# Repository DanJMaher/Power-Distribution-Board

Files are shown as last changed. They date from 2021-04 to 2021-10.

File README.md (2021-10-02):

Updated 3/29/21 - Dan Maher

C++/Arduino code for Kent State's Advanced Telerobotic's Lab's WRS robot power distribution system. The system distributes switched 24V and 12V power throughout the robot, monitors voltage, and communicates over USB and Bluetooth via JSON commands and messages. The system can also be controlled locally via an onboard OLED display and menu navigation buttons. 

The included serial_comm.py program is for testing communication between a PC and the Arduino. The system can also be tested via a Bluetooth terminal app for android or IOS.

Basic use:
1) Plug in an Arduino, send the code. 
2) run serial_comm.py (for basic communication) or power_monitor_pub.py for ROS integration on the 'power' topic.

When it boots, the Arduino tries to send a JSON message via serial:
{"request":"time"}

The python program responds via serial with the current time since midnight in seconds:
{"time": 70602, "alive": true}

Afterwards, the Arduino sends a status message via serial on the interval programmed in sendInterval in setup.cpp. The python program responds with {"alive": true} so that the Arduino knows that that communication path is good. The Arduino does not send another message until it receives a response.

The serial_comm.py program is just for troubleshooting, and copies the incoming/outgoing serial messages to the console so the user can see what's being sent/received.
---------------------------------------------------------------------------
REMOTE JSON COMMANDS
---------------------------------------------------------------------------
{"relay":[bool, bool]}		-		Sets individual relays to on/off

{"time":unsigned long}		-		Sync system time with long (in seconds)

{"shutdown":"now"}		-		Shuts down the system with code "remote"

---------------------------------------------------------------------------
INCOMING JSON MESSAGES
---------------------------------------------------------------------------

{"msg":int}			-		Message number

{"time":unsigned long}		-		Current timestamp

{"voltage:[float,float]}	-		Current voltages (11.1, 22.2)

{"relay":[bool,bool]}		-		Current relay status (11.1, 22.2)

{"comm status"[bool, bool]}	-		Current comm status path 1/2 (false is communication failure)

{"SHUTDOWN":string} 		-		System is shutting down for reason:
							"auto" - low voltage
							"remote" - remote serial command
							"button" - power button was pushed

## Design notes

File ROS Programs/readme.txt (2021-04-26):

power_distro_pub.py
-------------------
Simple program that checks the serial buffer, loads it into a json document, publishes it as the ROS topic "power" and prints it to the console. Responds to the power disto board with the current time if requested, otherwise just pings back to verify that the host is active.

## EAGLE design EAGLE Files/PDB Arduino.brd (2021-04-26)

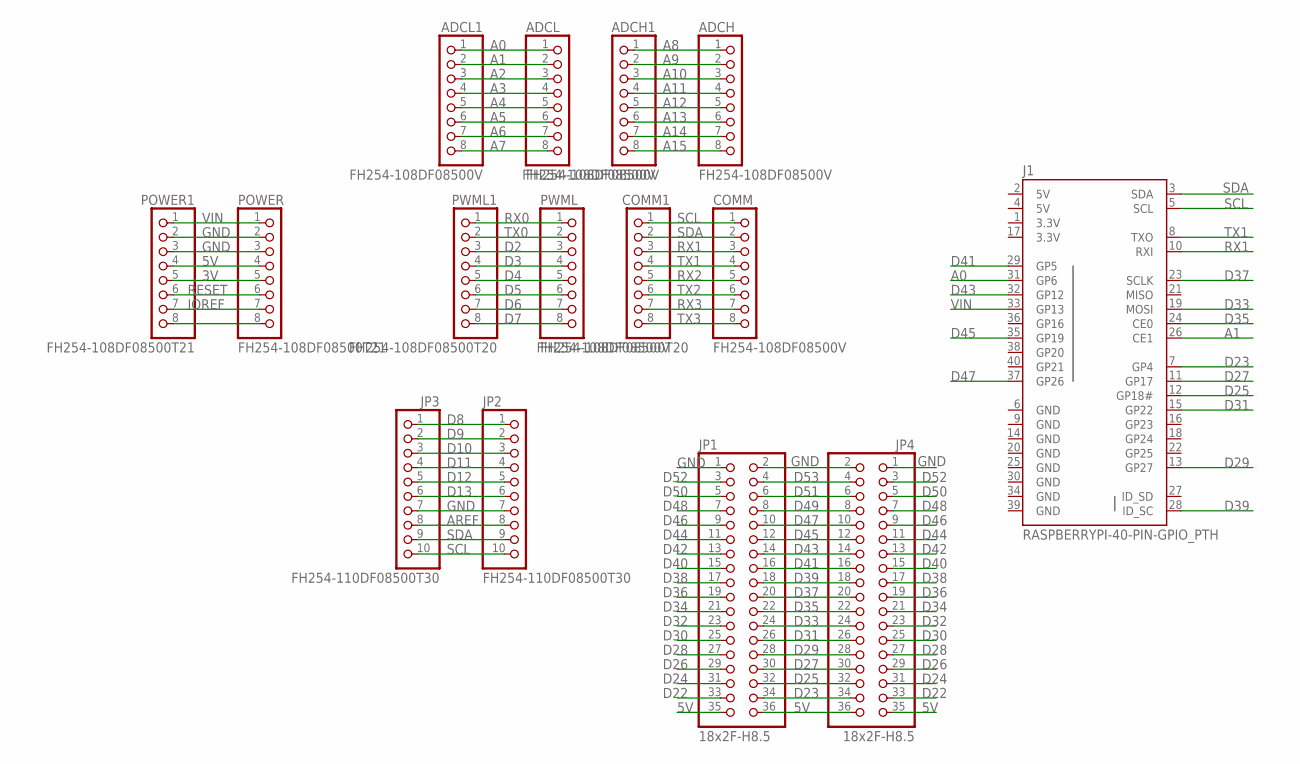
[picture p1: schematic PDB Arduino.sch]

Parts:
ADCH, ADCH1: FH254-108DF08500V; CONNETTORI_1X08
ADCL, ADCL1: FH254-108DF08500V; CONNETTORI_1X08
COMM, COMM1: FH254-108DF08500V; CONNETTORI_1X08
J1: RASPBERRYPI-40-PIN-GPIO_PTH; 2X20_SHROUDED
JP1, JP4: 18x2F-H8.5; CONNETTORI_2X18
JP2, JP3: FH254-110DF08500T30; CONNETTORI_1X10
POWER, POWER1: FH254-108DF08500T21; CONNETTORI_1X08
PWML, PWML1: FH254-108DF08500T20; CONNETTORI_1X08

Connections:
3.3V: J1.1 (3.3V), J1.17 (3.3V)
3V: POWER.5, POWER1.5
5V: J1.2 (5V), J1.4 (5V), JP1.35, JP1.36, JP4.35, JP4.36, POWER.4, POWER1.4
A0: ADCL.1, ADCL1.1, J1.31 (GP6)
A1: ADCL.2, ADCL1.2, J1.26 (CE1)
A2: ADCL.3, ADCL1.3
A3: ADCL.4, ADCL1.4
A4: ADCL.5, ADCL1.5
A5: ADCL.6, ADCL1.6
A6: ADCL.7, ADCL1.7
A7: ADCL.8, ADCL1.8
A8: ADCH.1, ADCH1.1
A9: ADCH.2, ADCH1.2
A10: ADCH.3, ADCH1.3
A11: ADCH.4, ADCH1.4
A12: ADCH.5, ADCH1.5
A13: ADCH.6, ADCH1.6
A14: ADCH.7, ADCH1.7
A15: ADCH.8, ADCH1.8
AREF: JP2.8, JP3.8
D2: PWML.3, PWML1.3
D3: PWML.4, PWML1.4
D4: PWML.5, PWML1.5
D5: PWML.6, PWML1.6
D6: PWML.7, PWML1.7
D7: PWML.8, PWML1.8
D8: JP2.1, JP3.1
D9: JP2.2, JP3.2
D10: JP2.3, JP3.3
D11: JP2.4, JP3.4
D12: JP2.5, JP3.5
D13: JP2.6, JP3.6
D22: JP1.33, JP4.33
D23: J1.7 (GP4), JP1.34, JP4.34
D24: JP1.31, JP4.31
D25: J1.12 (GP18#), JP1.32, JP4.32
D26: JP1.29, JP4.29
D27: J1.11 (GP17), JP1.30, JP4.30
D28: JP1.27, JP4.27
D29: J1.13 (GP27), JP1.28, JP4.28
D30: JP1.25, JP4.25
D31: J1.15 (GP22), JP1.26, JP4.26
D32: JP1.23, JP4.23
D33: J1.19 (MOSI), JP1.24, JP4.24
D34: JP1.21, JP4.21
D35: J1.24 (CE0), JP1.22, JP4.22
D36: JP1.19, JP4.19
D37: J1.23 (SCLK), JP1.20, JP4.20
D38: JP1.17, JP4.17
D39: J1.28 (ID_SC), JP1.18, JP4.18
D40: JP1.15, JP4.15
D41: J1.29 (GP5), JP1.16, JP4.16
D42: JP1.13, JP4.13
D43: J1.32 (GP12), JP1.14, JP4.14
D44: JP1.11, JP4.11
D45: J1.35 (GP19), JP1.12, JP4.12
D46: JP1.9, JP4.9
D47: J1.37 (GP26), JP1.10, JP4.10
D48: JP1.7, JP4.7
D49: JP1.8, JP4.8
D50: JP1.5, JP4.5
D51: JP1.6, JP4.6
D52: JP1.3, JP4.3
D53: JP1.4, JP4.4
GND: J1.6 (GND), J1.9 (GND), J1.14 (GND), J1.20 (GND), J1.25 (GND), J1.30 (GND), J1.34 (GND), J1.39 (GND), JP1.1, JP1.2, JP2.7, JP3.7, JP4.1, JP4.2, POWER.2, POWER.3, POWER1.2, POWER1.3
IOREF: POWER.7, POWER1.7
unnamed: POWER.8, POWER1.8
RESET: POWER.6, POWER1.6
RX0: PWML.1, PWML1.1
RX1: COMM.3, COMM1.3, J1.10 (RXI)
RX2: COMM.5, COMM1.5
RX3: COMM.7, COMM1.7
SCL: COMM.1, COMM1.1, J1.5 (SCL), JP2.10, JP3.10
SDA: COMM.2, COMM1.2, J1.3 (SDA), JP2.9, JP3.9
TX0: PWML.2, PWML1.2
TX1: COMM.4, COMM1.4, J1.8 (TXO)
TX2: COMM.6, COMM1.6
TX3: COMM.8, COMM1.8
VIN: J1.33 (GP13), POWER.1, POWER1.1

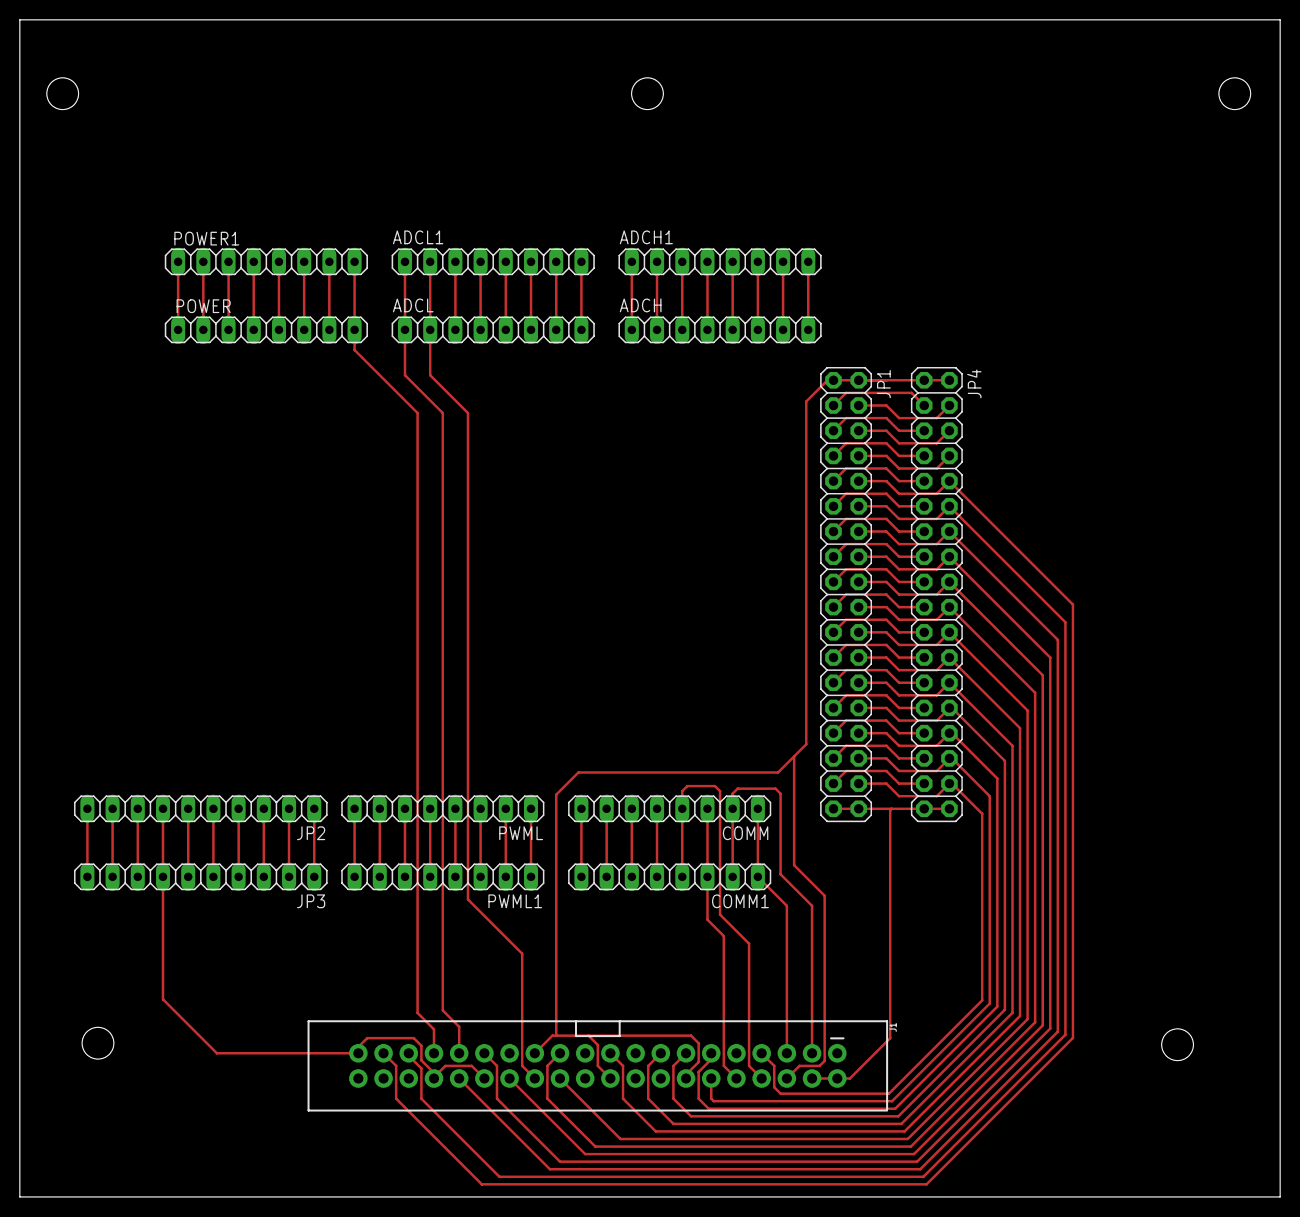
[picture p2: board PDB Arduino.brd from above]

Board: 2 copper layers, 127.0 x 118.6 mm, 15 parts (0 on the bottom side), 79 nets.

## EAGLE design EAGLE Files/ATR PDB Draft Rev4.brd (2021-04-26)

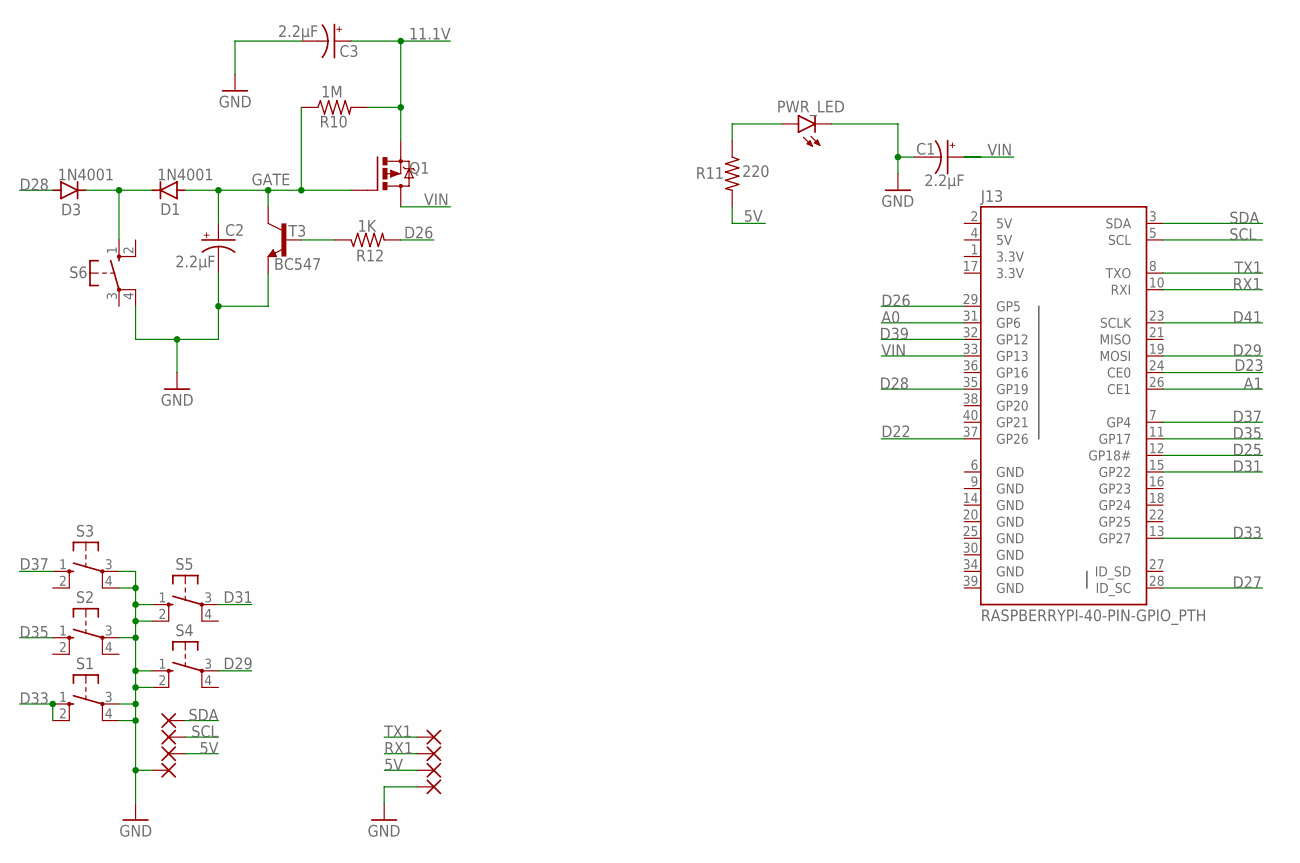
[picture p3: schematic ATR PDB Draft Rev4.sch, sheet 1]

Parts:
C1, C2, C3: 2.2µF; TT2D5
D1, D3: 1N4004; DO41-10
J13: RASPBERRYPI-40-PIN-GPIO_PTH; 2X20_SHROUDED
PAD1, PAD2, PAD3, PAD4, PAD5, PAD6, PAD7, PAD8: 1,6/0,8
PWR_LED: LED3MM
Q1: IRF9530; TO220BV
R10: 1M; 0207/10
R11: 220; 0204/7
R12: 1K; 0204/7
S1, S2, S3, S4, S5, S6: 10-XX; B3F-10XX
T3: BC547; TO92

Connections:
3.3V: J13.1 (3.3V), J13.17 (3.3V)
5V: J13.2 (5V), J13.4 (5V), PAD1.1, PAD7.1, R11.2
11.1V: C3.+, Q1.S, R10.2; also elsewhere on the board
A0: J13.31 (GP6); also elsewhere on the board
A1: J13.26 (CE1); also elsewhere on the board
D22: J13.37 (GP26); also elsewhere on the board
D23: J13.24 (CE0); also elsewhere on the board
D25: J13.12 (GP18#); also elsewhere on the board
D26: J13.29 (GP5), R12.2
D27: J13.28 (ID_SC); also elsewhere on the board
D28: D3.A, J13.35 (GP19)
D29: J13.19 (MOSI), S4.3
D31: J13.15 (GP22), S5.3
D33: J13.13 (GP27), S1.1 (S), S1.2 (S1)
D35: J13.11 (GP17), S2.1 (S)
D37: J13.7 (GP4), S3.1 (S)
D39: J13.32 (GP12); also elsewhere on the board
D41: J13.23 (SCLK); also elsewhere on the board
GATE: C2.+, D1.A, Q1.G, R10.1, T3.3 (C)
GND: C1.-, C2.-, C3.-, J13.6 (GND), J13.9 (GND), J13.14 (GND), J13.20 (GND), J13.25 (GND), J13.30 (GND), J13.34 (GND), J13.39 (GND), PAD3.1, PAD8.1, PWR_LED.K (C), S1.3, S1.4 (P1), S2.3, S3.3, S3.4 (P1), S4.1 (S), S4.2 (S1), S5.1 (S), S5.2 (S1), S6.4 (P1), T3.1 (E); also elsewhere on the board
unnamed: PWR_LED.A, R11.1
unnamed: D1.C, D3.C, S6.1 (S)
RX1: J13.10 (RXI), PAD2.1
SCL: J13.5 (SCL), PAD6.1
SDA: J13.3 (SDA), PAD5.1
T3-B: R12.1, T3.2 (B)
TX1: J13.8 (TXO), PAD4.1
VIN: C1.+, J13.33 (GP13), Q1.D

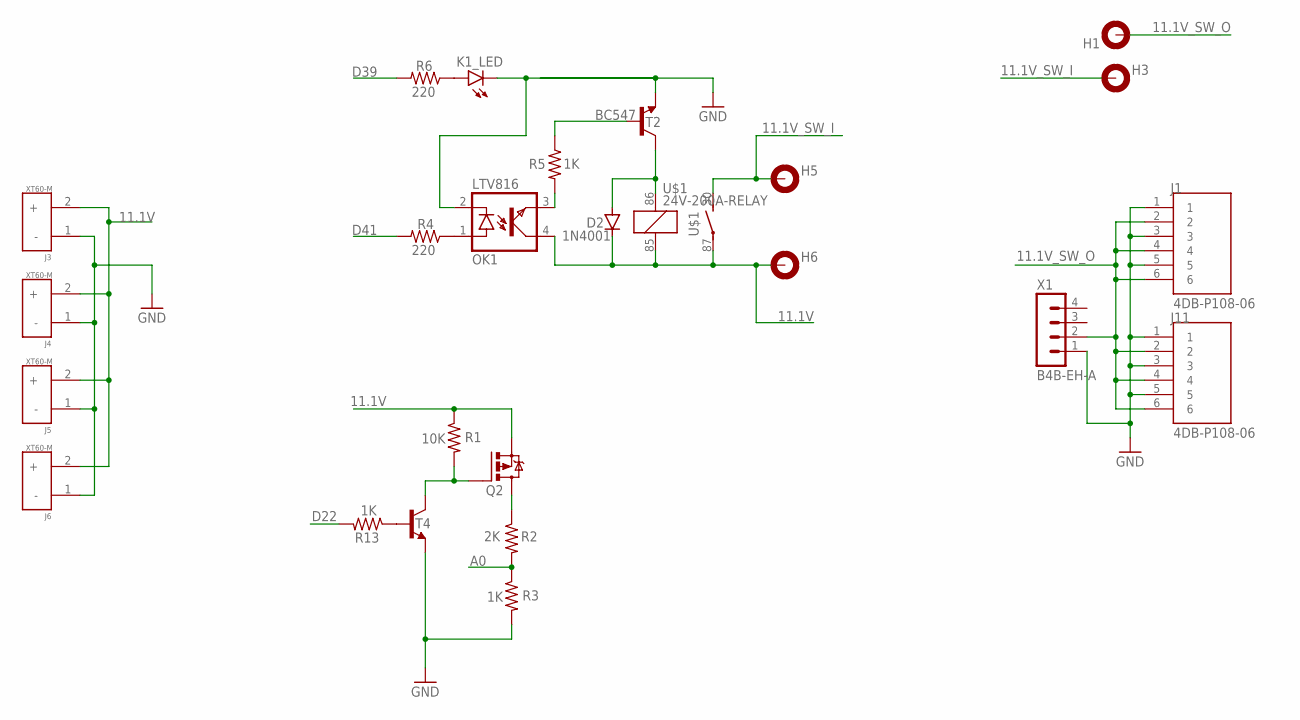
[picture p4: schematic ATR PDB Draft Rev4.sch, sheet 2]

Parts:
D2: 1N4004; DO41-10
H1, H3, H5, H6: MOUNT-PAD-ROUND3.0; 3,0-PAD
J1, J11: 4DB-P108-06; TE_2-1437667-9
J3, J4, J5, J6: XT60-M; AMASS_XT60-M
K1_LED: LED3MM
OK1: LTV816; DIL04
Q2: IRF9530; TO220BV
R1: 10K; 0204/7
R2: 2K; 0204/7
R3, R5, R13: 1K; 0204/7
R4, R6: 220; 0204/7
T2, T4: BC547; TO92
U$1: 24V-200A-RELAY
X1: B4B-EH-A

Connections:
11.1V: D2.C, H6.B3,0, J3.2 (+), J4.2 (+), J5.2 (+), J6.2 (+), OK1.4 (COL), Q2.S, R1.1, U$1.85, U$1.87; also elsewhere on the board
11.1V_SW_I: H3.B3,0, H5.B3,0, U$1.30
11.1V_SW_O: H1.B3,0, J1.2, J1.4, J1.6, J11.2, J11.4, J11.6, X1.2
A0: R2.2, R3.1; also elsewhere on the board
D22: R13.2; also elsewhere on the board
D39: R6.2; also elsewhere on the board
D41: R4.2; also elsewhere on the board
DRAIN1: Q2.D, R2.1
GATE1: Q2.G, R1.2, T4.3 (C)
GND: J1.1, J1.3, J1.5, J3.1 (-), J4.1 (-), J5.1 (-), J6.1 (-), J11.1, J11.3, J11.5, K1_LED.K (C), OK1.2 (C), R3.2, T2.1 (E), T4.1 (E), X1.1; also elsewhere on the board
unnamed: OK1.1 (A), R4.1
unnamed: K1_LED.A, R6.1
unnamed: R13.1, T4.2 (B)
unnamed: OK1.3 (EMIT), R5.2
unnamed: R5.1, T2.2 (B)
unnamed: D2.A, T2.3 (C), U$1.86

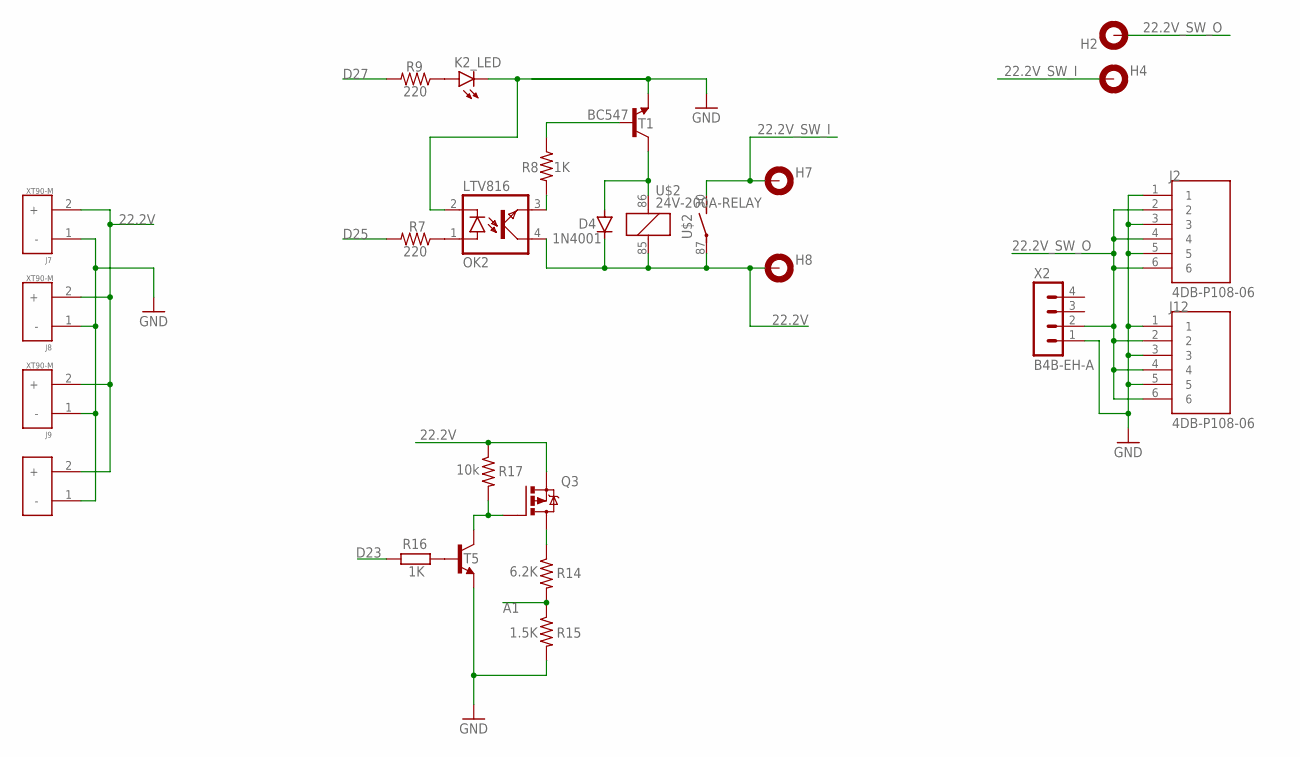
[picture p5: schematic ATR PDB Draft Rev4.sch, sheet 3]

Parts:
D4: 1N4004; DO41-10
H2, H4, H7, H8: MOUNT-PAD-ROUND3.0; 3,0-PAD
J2, J12: 4DB-P108-06; TE_2-1437667-9
J7, J8, J9, J10: XT90-M; AMASS_XT90-M
K2_LED: LED3MM
OK2: LTV816; DIL04
Q3: IRF9530; TO220BV
R7, R9: 220; 0204/7
R8, R16: 1K; 0204/7
R14: 6.2K; 0204/7
R15: 1.5K; 0207/10
R17: 10k; 0204/7
T1, T5: BC547; TO92
U$2: 24V-200A-RELAY
X2: B4B-EH-A

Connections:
22.2V: D4.C, H8.B3,0, J7.2 (+), J8.2 (+), J9.2 (+), J10.2 (+), OK2.4 (COL), Q3.S, R17.1, U$2.85, U$2.87
22.2V_SW_I: H4.B3,0, H7.B3,0, U$2.30
22.2V_SW_O: H2.B3,0, J2.2, J2.4, J2.6, J12.2, J12.4, J12.6, X2.2
A1: R14.2, R15.1; also elsewhere on the board
D23: R16.2; also elsewhere on the board
D25: R7.2; also elsewhere on the board
D27: R9.2; also elsewhere on the board
DRAIN2: Q3.D, R14.1
GATE2: Q3.G, R17.2, T5.3 (C)
GND: J2.1, J2.3, J2.5, J7.1 (-), J8.1 (-), J9.1 (-), J10.1 (-), J12.1, J12.3, J12.5, K2_LED.K (C), OK2.2 (C), R15.2, T1.1 (E), T5.1 (E), X2.1; also elsewhere on the board
unnamed: OK2.3 (EMIT), R8.2
unnamed: R8.1, T1.2 (B)
unnamed: D4.A, T1.3 (C), U$2.86
unnamed: OK2.1 (A), R7.1
unnamed: K2_LED.A, R9.1
unnamed: R16.1, T5.2 (B)

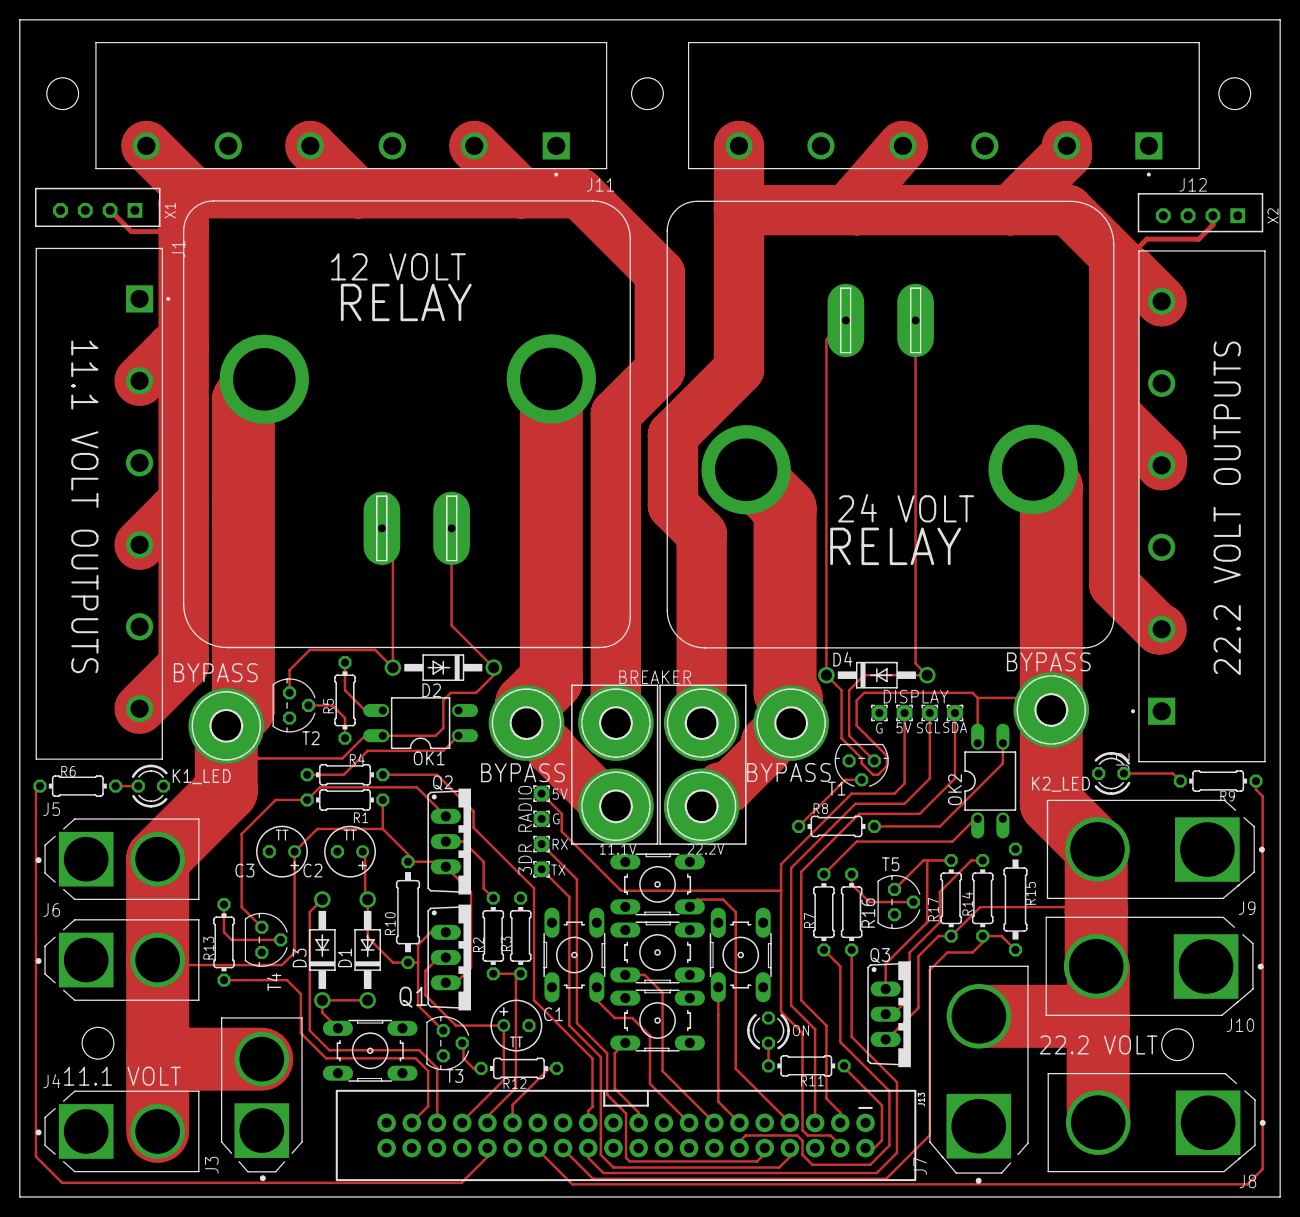
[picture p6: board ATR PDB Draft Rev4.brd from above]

Board: 2 copper layers, 127.0 x 118.6 mm, 76 parts (0 on the bottom side), 49 nets.

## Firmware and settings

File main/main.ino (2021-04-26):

/**
   main.ino
 * *************************
   For Kent State's ATR Lab
   03/19/2021
   Dan Maher

   Code for operation of the custom
   power distribution board (PDB) PCB

 * *******************************************************

 * *******************************************************
**/

#include "setup.h"

/*****************************/
/************MAIN*************/
/*****************************/
void loop() {
  
  unsigned long currentMillis = millis();
  // Check if power button has been pressed
  Supervision::pwrButtonRead();

  // Check current system state
  if (currentMillis - prevSuperviseMillis > supervisionInterval) {
    Supervision::supervise();
    prevSuperviseMillis = currentMillis;
  }

  // Refresh display
  if (Screen::menuMode) {
    Screen::updateDisplay(&data);
  }
  else if (currentMillis - prevDisplayMillis > displayInterval) {
    Screen::updateDisplay(&data);
    prevDisplayMillis = currentMillis;
  }

  // Send serial data
  if (currentMillis - prevSendMillis > sendInterval) {
    //Serial.println("SEND_SERIAL");
    if (usb.active)
      usb.sendData();
    if (wls.active)
      wls.sendData();
    prevSendMillis = currentMillis;
  }

  // Check incoming serial buffer for commands
  if (usb.active)
    usb.checkSerialBuffer();
  if (wls.active) {
    wls.checkSerialBuffer();
  }
  
  //Serial.println("MAIN_LOOP");
  //delay(1000);
}

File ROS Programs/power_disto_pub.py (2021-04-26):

#!/usr/bin/env python

import rospy
import serial
import json
from datetime import datetime
from std_msgs.msg import String

ser = serial.Serial('/dev/ttyACM0', baudrate = 115200, timeout = 7)

def power_monitor():
    pub = rospy.Publisher('power', String, queue_size=10)
    rospy.init_node('power_monitor', anonymous=True)
    rate = rospy.Rate(10)
    while not rospy.is_shutdown():
        powerData = getTransmission()
        
        if 'request' in powerData:
            updateTime(powerData)
            
        sendResponse(powerData)
        rospy.loginfo(powerData)
        pub.publish(powerData)
        rate.sleep()

def getTransmission():
    bufferData = ser.readline().decode("ascii")
    powerJson = json.loads(bufferData)
    return powerJson

def updateTime(jsonDoc):
    if jsonDoc['request'] == 'time':
            now = datetime.now()
            seconds_since_midnight = (now - now.replace(hour=0, minute=0, second=0, microsecond=0)).total_seconds()
            json_time = json.dumps({'time':int(seconds_since_midnight),'alive':True})
            ser.write(json_time.encode("ascii"))

def sendResponse(jsonDoc):
        pdbResponse = json.dumps({'alive':True})
        ser.write(pdbResponse.encode("ascii"))
        
if __name__ == '__main__':
    try:
        power_monitor()
    except rospy.ROSInterruptException:
        pass

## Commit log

2021-04-01 Added wireless comm and changed Comm class from static to instanced
2021-04-02 added screen class and some basic screen functionality. Can now display voltage and relay status actively
2021-04-06 Single page menu working with 11.1v relay on/off
2021-04-26 Added basic ROS publisher topic and fixed speed bugs due to Serial.readString. Made a custom algorithm instead
    [main.ino, power_disto_pub.py, screen.cpp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]
2021-04-26 Added EAGLE .brd and .sch files
    [ATR PDB Draft Rev4.brd, ATR PDB Draft Rev4.sch, PDB Arduino.brd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]

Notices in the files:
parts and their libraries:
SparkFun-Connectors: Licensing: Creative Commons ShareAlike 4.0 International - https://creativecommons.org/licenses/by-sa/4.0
